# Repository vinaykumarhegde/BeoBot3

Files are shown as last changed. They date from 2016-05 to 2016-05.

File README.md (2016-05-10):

# BeoBot3

#### Mobile Robot for Indoor Navigation
--

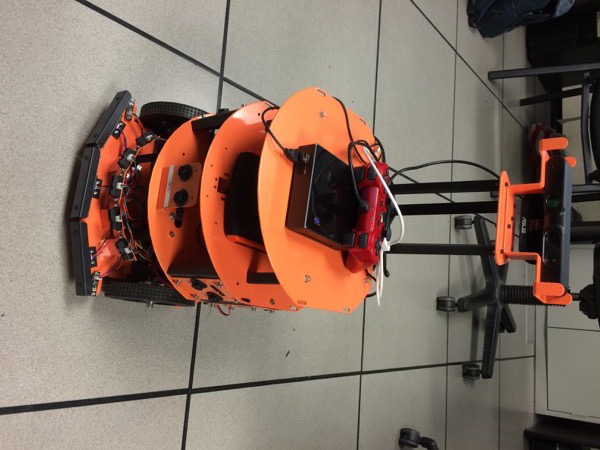
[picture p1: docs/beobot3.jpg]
BeoBot3


#### Specifications:
- Mobile base with wheel encoders
- 6 Ultrasound sensors for distance measurement
- 3 Front facing bumpers
- 11 IR sensors for distance measurement
- 4 Down facing IR sensors for cliff detection
- 1 Asus Xtion Pro Live RGBD camera
- Gigabyte iBrix mini PC with Ubuntu 14.04 and ROS Indigo

#### System Architecture:
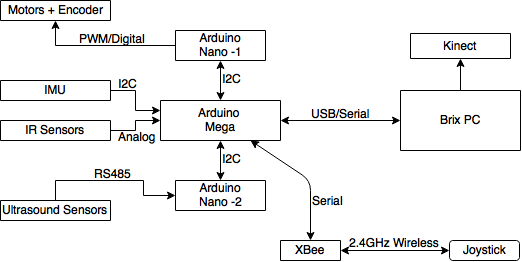
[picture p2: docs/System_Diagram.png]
Sys_arch


#### Software Components:
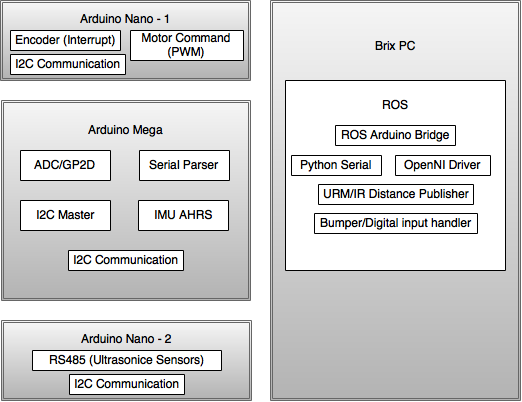
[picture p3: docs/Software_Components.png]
Sofware_components


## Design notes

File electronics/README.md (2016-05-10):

##BeoBot3
####Electronics
---

####Architecture:

####Resources:

* Schematic:
* Datasheets:

####Known Issues:
* Remove RS485 RX/TX jumpers while programming Nano-2. This connection is shared between programming interface (Serial) and MAX1348 (RS485 transciver).
* XBEE should always be on TTL1 port.
* Ignore TTL3/IMU markings on GMR board. 10-DOF IMU connects as I2C slave to Mega.
* ROS/Arduino Mega not responding:
	- Solution: This happens because Mega can not talk to nano-1 or nano-2. In the setup phase, Mega looks for I2C slaves to be connected. 
	- Also, make sure GMR board is powered ON. I2C pull up resistors use VCC from GMR board, not from USB connections.
* GMR Board has SX3478 and schematic has GS3478. This are pin compatible alternatives.

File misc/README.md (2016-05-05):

## BeoBot3 
#### Miscellaneous Files
---
This directory contains miscellaneous files used for the project. Designs for all 3D printed parts are stored here.

### Asus Xtio Pro Live Mount
This mount can be used to mount Asus Xtio Pro Live camera on the robot. This can be snapped on to rotating fixture on Asus Xtion camera.

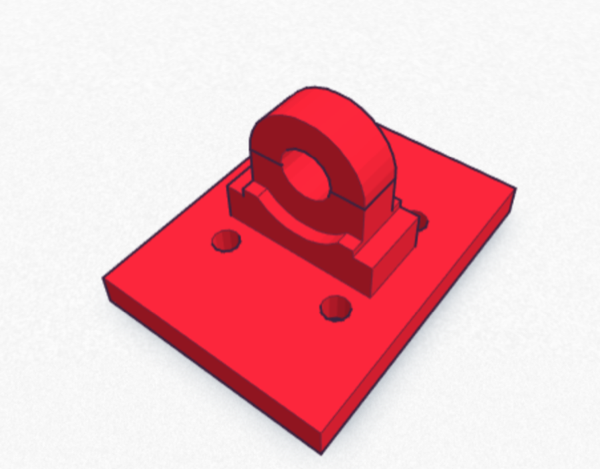
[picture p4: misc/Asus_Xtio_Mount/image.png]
Asus_Xtion


Design location: [Tinkercad](https://tinkercad.com/things/gU7ryKgmKkC) 

### Pan-Tilt Camera Mount
This mount is used to hold [ODROID webcam] (http://www.hardkernel.com/main/products/prdt_info.php?g_code=G137517754892) and has 2-Degrees of freedom for rotation. This uses [9G micro servos] (http://www.amazon.com/RioRand-micro-Helicopter-Airplane-Controls/dp/B00M8RGGFG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) for pan and tilt movements and can be controlled by PWM signal. 

This can be used to implement object tracking or surprise detection algorithm on robot.

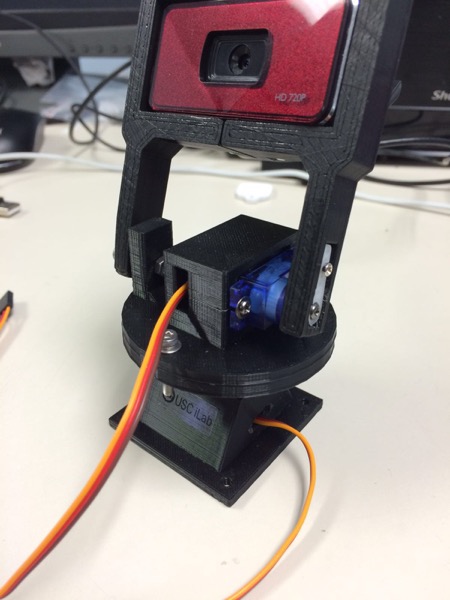
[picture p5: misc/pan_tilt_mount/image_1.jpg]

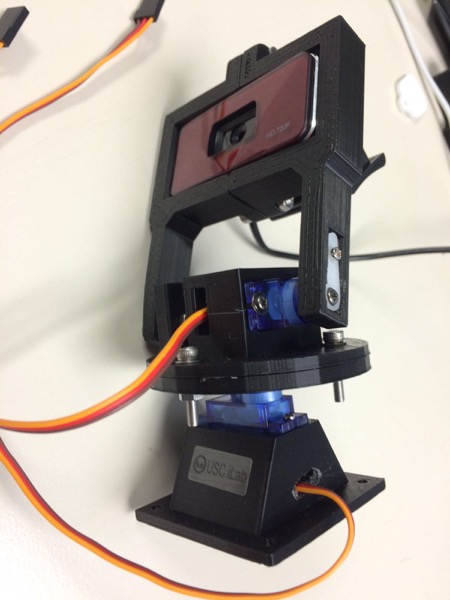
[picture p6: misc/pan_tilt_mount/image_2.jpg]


##### Important notes:
* [Datasheet] (http://www.micropik.com/PDF/SG90Servo.pdf)
* Connections:
	- Orange: PWM Input
	- Red: Vcc
	- Brown: Gnd
* Gears are very soft (they are plastic) and break if you try to twist it with force!
* Thingiverse link: [Thingiverse] (http://www.thingiverse.com/thing:1540658)

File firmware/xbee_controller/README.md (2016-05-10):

## HCR Robot RC Controller

RC Model: [DF Robot Wireless Gamepad V2.0](http://www.dfrobot.com/index.php?route=product/product&product_id=858#.Vwr5imNWKn0) [[Wiki]] (http://www.dfrobot.com/wiki/index.php/Wirless_GamePad_V2.0_(SKU:DFR0182))

### Gamepad:
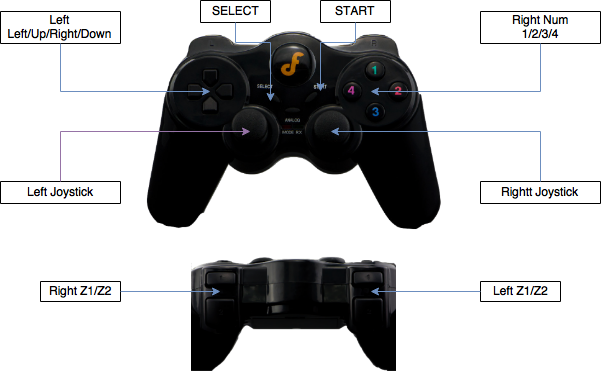
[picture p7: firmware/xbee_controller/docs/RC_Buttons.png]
RC_Buttons


### Specifications:
* Enable/Disable Robot
* Give Linear/Angular Velocities to Robot
* Emergency Stop
* Vibration Feedback

### Key Associations:

| Function | Key | 
| ---| --- |
| Start| Push and Hold START for 1 second |
| Emergency Stop | Right num (1) |
| Stop the robot | Left/Right Z1 |
| Linear Velocity | Left/Right Z2 + Left Joystick |
| Angular Velocity | Left/Right Z2 + Right Joystick | 
| Calibrate Joysticks | Left Z1 + Right num (2) |
| Change Linear Velocity| Right Z1 + Left Up/Down Arrow|
| Change Linear Velocity| Right Z1 + Left Left/Right Arrow|
| Enable ROS | Press and Hold SELECT for 3 seconds |

### TO-DO:
* Implement handshaking to ensure the commands are received by the robot.
* Adjust/fine-tune the joystick.

### Warning:
* Do not press ANALOG button. This freezes all the joystic buttons (Temporary fix: Restart the controller)
* (IMPORTANT!!) While connecting Arduino programming header, make sure the it's as shown in the image below: 

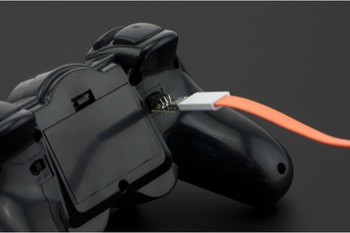
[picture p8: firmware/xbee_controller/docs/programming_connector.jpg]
Programming


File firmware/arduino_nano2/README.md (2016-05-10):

## HCRBot GMR n2 driver

URM04 driver.

Addresses:
 *      UR_L2N  - 0x11
 *      UR_L2NW - 0x12
 *      UR_L2NE - 0x13
 *      UR_L2S  - 0x14
 *      UR_L2SW - 0x15
 *      UR_L2SE - 0x16

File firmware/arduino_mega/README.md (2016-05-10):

### hcrbot_gmr_mega

##### History:
* Initial Version: [ROS Arduino Bridge](http://wiki.ros.org/ros_arduino_bridge)
* Current: Added Support for DFRobot HCRBot motor and encoders

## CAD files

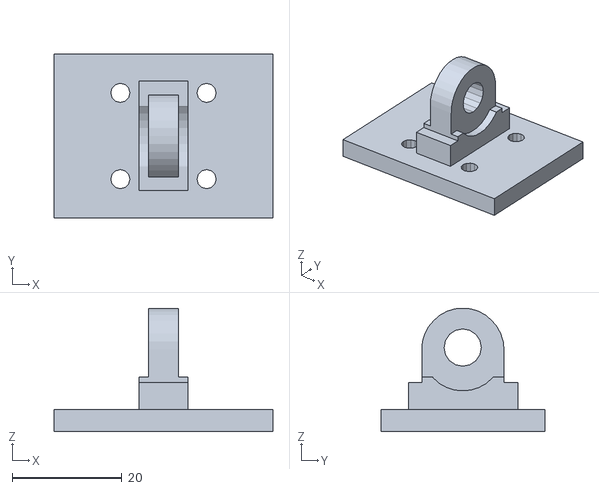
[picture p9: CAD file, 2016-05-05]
misc/Asus_Xtio_Mount/asus_xtion_pro_live_mount.stl
40.0 x 30.0 x 22.5

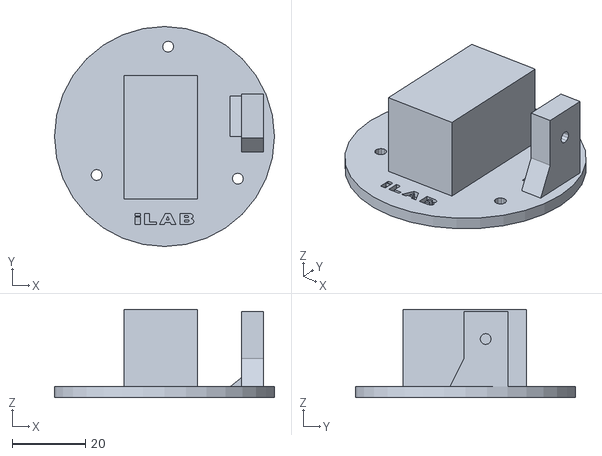
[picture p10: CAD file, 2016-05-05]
misc/pan_tilt_mount/pan-tilt-middle-plate-1.stl
60.0 x 60.0 x 24.1

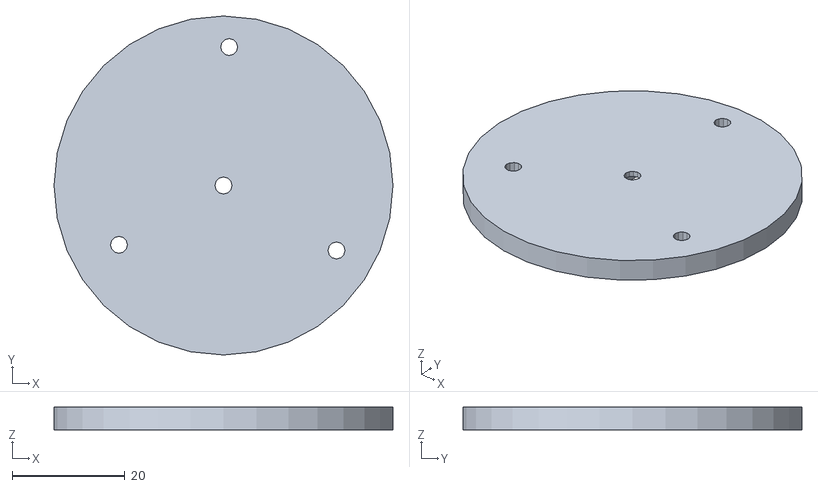
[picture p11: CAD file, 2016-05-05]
misc/pan_tilt_mount/pan-tilt-middle-plate-2.stl
60.0 x 60.0 x 4.00

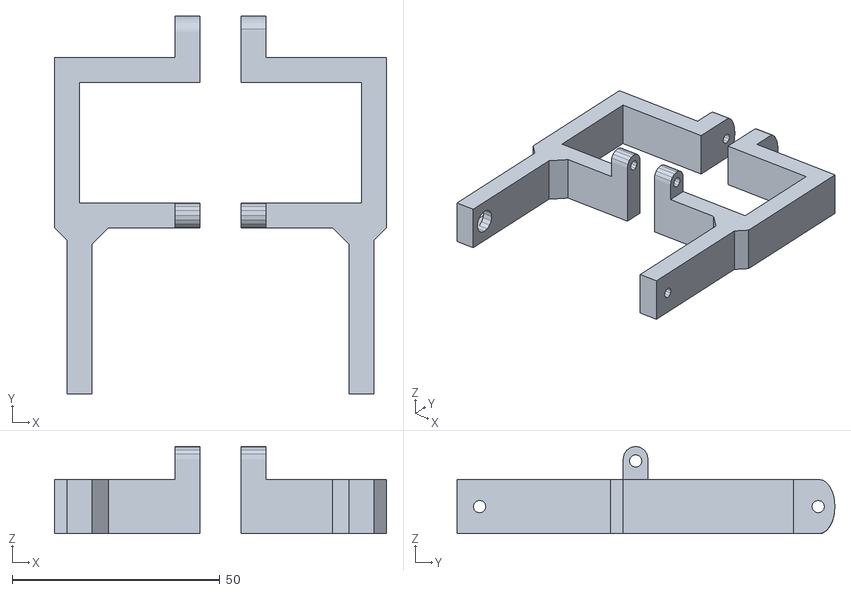
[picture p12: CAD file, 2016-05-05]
misc/pan_tilt_mount/pan-tilt-camera-holder.stl
80.0 x 91.0 x 21.0

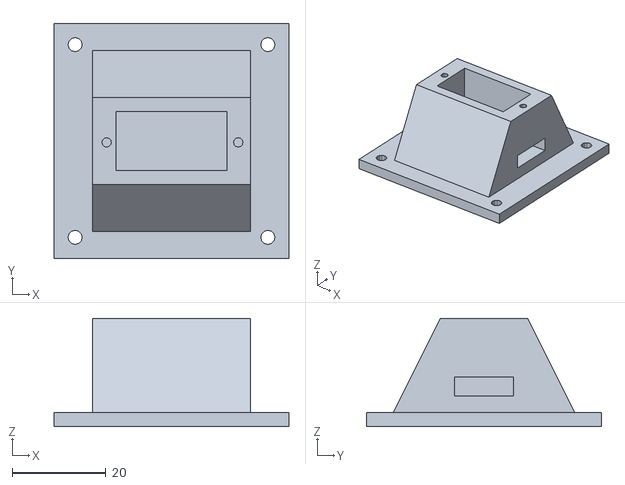
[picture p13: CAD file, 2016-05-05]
misc/pan_tilt_mount/pan-tilt-base.stl
50.0 x 50.0 x 23.0

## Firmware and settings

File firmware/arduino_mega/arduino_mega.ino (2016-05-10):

/*********************************************************************
 *  ROSArduinoBridge
 
    A set of simple serial commands to control a differential drive
    robot and receive back sensor and odometry data. Default 
    configuration assumes use of an Arduino Mega + Pololu motor
    controller shield + Robogaia Mega Encoder shield.  Edit the
    readEncoder() and setMotorSpeed() wrapper functions if using 
    different motor controller or encoder method.

    Created for the Pi Robot Project: http://www.pirobot.org
    and the Home Brew Robotics Club (HBRC): http://hbrobotics.org
    
    Authors: Patrick Goebel, James Nugen

    Inspired and modeled after the ArbotiX driver by Michael Ferguson
    
    Software License Agreement (BSD License)

    Copyright (c) 2012, Patrick Goebel.
    All rights reserved.

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
    THIS SOFTWARE IS PROVIDED BY THE COPYRIGHT HOLDERS AND CONTRIBUTORS
    "AS IS" AND ANY EXPRESS OR IMPLIED WARRANTIES, INCLUDING, BUT NOT
    LIMITED TO, THE IMPLIED WARRANTIES OF MERCHANTABILITY AND FITNESS
    FOR A PARTICULAR PURPOSE ARE DISCLAIMED. IN NO EVENT SHALL THE
    COPYRIGHT OWNER OR CONTRIBUTORS BE LIABLE FOR ANY DIRECT, INDIRECT,
    INCIDENTAL, SPECIAL, EXEMPLARY, OR CONSEQUENTIAL DAMAGES (INCLUDING,
    BUT NOT LIMITED TO, PROCUREMENT OF SUBSTITUTE GOODS OR SERVICES;
    LOSS OF USE, DATA, OR PROFITS; OR BUSINESS INTERRUPTION) HOWEVER
    CAUSED AND ON ANY THEORY OF LIABILITY, WHETHER IN CONTRACT, STRICT
    LIABILITY, OR TORT (INCLUDING NEGLIGENCE OR OTHERWISE) ARISING IN
    ANY WAY OUT OF THE USE OF THIS SOFTWARE, EVEN IF ADVISED OF THE
 *  POSSIBILITY OF SUCH DAMAGE.
 *********************************************************************/

#include <Wire.h>

#define USE_BASE      // Enable the base controller code
//#undef USE_BASE     // Disable the base controller code

/* Define the motor controller and encoder library you are using */
#ifdef USE_BASE
   /* The Pololu VNH5019 dual motor driver shield */
   //#define POLOLU_VNH5019

   /* The Pololu MC33926 dual motor driver shield */
   //#define POLOLU_MC33926

   /* DFRobot HCR GMR Board Arduino Nano-1 motor driver.*/
   #define DFRHCR_N1_DRIVER

   /* DFRobot HCR GMR Encoders attached to Nano 1*/
   #define DFRHCR_N1_ENCODER
   
   /* The RoboGaia encoder shield */
   //#define ROBOGAIA
   
   /* Encoders directly attached to Arduino board */
   //#define ARDUINO_ENC_COUNTER
#endif

//#define USE_SERVOS  // Enable use of PWM servos as defined in servos.h
#undef USE_SERVOS     // Disable use of PWM servos

/* Serial port baud rate */
#define BAUDRATE    115200

/* Maximum PWM signal */
#define MAX_PWM        255

#if defined(ARDUINO) && ARDUINO >= 100
#include "Arduino.h"
#else
#include "WProgram.h"
#endif

/* Include definition of serial commands */
#include "commands.h"

/* Sensor functions */
#include "sensors.h"

/* Include servo support if required */
#ifdef USE_SERVOS
   #include <Servo.h>
   #include "servos.h"
#endif

#ifdef USE_BASE
  /* Motor driver function definitions */
  #include "motor_driver.h"

  /* Encoder driver function definitions */
  #include "encoder_driver.h"

  /* PID parameters and functions */
  #include "diff_controller.h"

  /* Run the PID loop at 30 times per second */
  #define PID_RATE           100     // Hz

  /* Convert the rate into an interval */
  const int PID_INTERVAL = 1000 / PID_RATE;
  
  /* Track the next time we make a PID calculation */
  unsigned long nextPID = PID_INTERVAL;

  /* Stop the robot if it hasn't received a movement command
   in this number of milliseconds */
  #define AUTO_STOP_INTERVAL 2000
  long lastMotorCommand = AUTO_STOP_INTERVAL;
#endif

/* Variable initialization */

// A pair of varibles to help parse serial commands (thanks Fergs)
int arg = 0;
int index = 0;

// Variable to hold an input character
char chr;

// Variable to hold the current single-character command
char cmd;

// Character arrays to hold the first and second arguments
char argv1[16];
char argv2[16];

// The arguments converted to integers
long arg1;
long arg2;

// Variable for ROS compatibility
bool ROSEnabled = true;


/* Clear the current command parameters */
void resetCommand() {
  cmd = NULL;
  memset(argv1, 0, sizeof(argv1));
  memset(argv2, 0, sizeof(argv2));
  arg1 = 0;
  arg2 = 0;
  arg = 0;
  index = 0;
}

/* Run a command.  Commands are defined in commands.h */
int runCommand() {
  int i = 0;
  char *p = argv1;
  char *str;
  int pid_args[4];
  arg1 = atoi(argv1);
  arg2 = atoi(argv2);
  
  switch(cmd) {
  case GET_BAUDRATE:
    Serial.println(BAUDRATE);
    break;
  case ANALOG_READ:
    Serial.println(analogRead(arg1));
    break;
  case DIGITAL_READ:
    Serial.println(digitalRead(arg1));
    break;
  case ANALOG_WRITE:
    analogWrite(arg1, arg2);
    Serial.println("OK"); 
    break;
  case DIGITAL_WRITE:
    if (arg2 == 0) digitalWrite(arg1, LOW);
    else if (arg2 == 1) digitalWrite(arg1, HIGH);
    Serial.println("OK"); 
    break;
  case PIN_MODE:
    if (arg2 == 0) pinMode(arg1, INPUT);
    else if (arg2 == 1) pinMode(arg1, OUTPUT);
    Serial.println("OK");
    break;
  case PING:
    Serial.println(Ping(arg1));
    break;

//  case URM04:
//    char dsfg = readURM();
//    for(){
//      Serial.write();
//    } 
//    Serial.print("\n");
//    Serial.println("OK");
//    break;
#ifdef USE_SERVOS
  case SERVO_WRITE:
    servos[arg1].write(arg2);
    Serial.println("OK");
    break;
  case SERVO_READ:
    Serial.println(servos[arg1].read());
    break;
#endif
    
#ifdef USE_BASE
  case READ_ENCODERS:
    Serial.print(readEncoder(LEFT));
    Serial.print(" ");
    Serial.println(readEncoder(RIGHT));
    break;
   case RESET_ENCODERS:
    resetEncoders();
    resetPID();
    Serial.println("OK");
    break;
  case MOTOR_SPEEDS:
    /* Reset the auto stop timer */
    lastMotorCommand = millis();
    if (arg1 == 0 && arg2 == 0) {
      setMotorSpeeds(0, 0);
      moving = 0;
    }
    else moving = 1;
    leftPID.TargetTicksPerFrame = arg1;
    rightPID.TargetTicksPerFrame = arg2;
    Serial.println("OK"); 
    break;
  case UPDATE_PID:
    while ((str = strtok_r(p, ":", &p)) != '\0') {
       pid_args[i] = atoi(str);
       i++;
    }
    Kp = pid_args[0];
    Kd = pid_args[1];
    Ki = pid_args[2];
    Ko = pid_args[3];
    Serial.println("OK");
    break;
#endif
  default:
    Serial.println("Invalid Command");
    break;
  }
}

/* Setup function--runs once at startup. */
void setup() {
  Serial.begin(BAUDRATE);
  Serial1.begin(BAUDRATE);

// Initialize the motor controller if used */
#ifdef USE_BASE
  #ifdef ARDUINO_ENC_COUNTER
    //set as inputs
    DDRD &= ~(1<<LEFT_ENC_PIN_A);
    DDRD &= ~(1<<LEFT_ENC_PIN_B);
    DDRC &= ~(1<<RIGHT_ENC_PIN_A);
    DDRC &= ~(1<<RIGHT_ENC_PIN_B);
    
    //enable pull up resistors
    PORTD |= (1<<LEFT_ENC_PIN_A);
    PORTD |= (1<<LEFT_ENC_PIN_B);
    PORTC |= (1<<RIGHT_ENC_PIN_A);
    PORTC |= (1<<RIGHT_ENC_PIN_B);
    
    // tell pin change mask to listen to left encoder pins
    PCMSK2 |= (1 << LEFT_ENC_PIN_A)|(1 << LEFT_ENC_PIN_B);
    // tell pin change mask to listen to right encoder pins
    PCMSK1 |= (1 << RIGHT_ENC_PIN_A)|(1 << RIGHT_ENC_PIN_B);
    
    // enable PCINT1 and PCINT2 interrupt in the general interrupt mask
    PCICR |= (1 << PCIE1) | (1 << PCIE2);
  #elif defined DFRHCR_N1_ENCODER
    Serial.println("Master Arduino started...");
    Wire.begin();
  #endif
  initMotorController();
  resetPID();
#endif
/* Attach servos if used */
#ifdef USE_SERVOS
  int i;
  for (i = 0; i < N_SERVOS; i++) {
    servos[i].attach(servoPins[i]);
  }
#endif
  
}


/* Enter the main loop.  Read and parse input from the serial port
   and run any valid commands. Run a PID calculation at the target
   interval and check for auto-stop conditions.
*/
void loop() {
  if(Serial1.available()){
    bool ROSEnabled = false;
    while(Serial1.available()){
    // Read the next character
    chr = Serial1.read();
    Serial.print(chr);
    // Terminate a command with a CR
    if(chr == '!'){
      // Enable the ROS functionality
      ROSEnabled = true;
    }
    else if (chr == 13) {
      if (arg == 1) argv1[index] = NULL;
      else if (arg == 2) argv2[index] = NULL;
      runCommand();
      resetCommand();
    }
    // Use spaces to delimit parts of the command
    else if (chr == ' ') {
      // Step through the arguments
      if (arg == 0) arg = 1;
      else if (arg == 1)  {
        argv1[index] = NULL;
        arg = 2;
        index = 0;
      }
      continue;
    }
    else {
      if (arg == 0) {
        // The first arg is the single-letter command
        cmd = chr;
      }
      else if (arg == 1) {
        // Subsequent arguments can be more than one character
        argv1[index] = chr;
        index++;
      }
      else if (arg == 2) {
        argv2[index] = chr;
        index++;
      }
    }    
    }
  }
  
  while (ROSEnabled && Serial.available() > 0) {
    // Read the next character
    chr = Serial.read();

    // Terminate a command with a CR
    if (chr == 13) {
      if (arg == 1) argv1[index] = NULL;
      else if (arg == 2) argv2[index] = NULL;
      runCommand();
      resetCommand();
    }
    // Use spaces to delimit parts of the command
    else if (chr == ' ') {
      // Step through the arguments
      if (arg == 0) arg = 1;
      else if (arg == 1)  {
        argv1[index] = NULL;
        arg = 2;
        index = 0;
      }
      continue;
    }
    else {
      if (arg == 0) {
        // The first arg is the single-letter command
        cmd = chr;
      }
      else if (arg == 1) {
        // Subsequent arguments can be more than one character
        argv1[index] = chr;
        index++;
      }
      else if (arg == 2) {
        argv2[index] = chr;
        index++;
      }
    }
  }
  
// If we are using base control, run a PID calculation at the appropriate intervals
#ifdef USE_BASE
  if (millis() > nextPID) {
    updatePID();
    nextPID += PID_INTERVAL;
  }
  
  // Check to see if we have exceeded the auto-stop interval
  if ((millis() - lastMotorCommand) > AUTO_STOP_INTERVAL) {;
    setMotorSpeeds(0, 0);
    moving = 0;
  }

#endif
}

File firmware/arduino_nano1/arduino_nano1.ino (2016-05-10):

/*
 * Program for Nano 1
 * 
 */

#include <Wire.h>
//#define LOGGING 1
#undef LOGGING


// Pins
#define R_PWM 9  //M1 Speed Control
#define L_PWM 11 //M2 Speed Control
#define R_DIR 8  //M1 Direction Control
#define L_DIR 10 //M1 Direction Control
#define R_ENC_OTHER 4 // Encoder Pin A
#define R_ENC_INT 2 // Int 0; Encode Pin B
#define L_ENC_INT 3 // Int 1; Encoder Pin A
#define L_ENC_OTHER 5 //Encode Pin B

#define MINPWM 50 //Minimum PWM for the motor, below this static friction stops the motor from spinning
#define STATICPULSEWIDTH 100 //Pulse time to avoid static friction in gears.

// Buffers
#define CMDBUFFER 10 // Command buffer.

// Other
#define MAXSPEED 100 // In mm/s
#define BASEWIDTH 285 // in mm
#define WHEELDIAMETER 136 // in mm
#define N1_I2C_ADDR 0x10
#define BAUDRATE 115200


// Variables
volatile long lTicks;
volatile long rTicks;

void leftTicks(){
  if(digitalRead(L_ENC_OTHER))
    lTicks--;
  else
    lTicks++;
}

// Clockwise rotation will increment ticks and 
// anti clockwise will decrease the count
void rightTicks(){
  if(digitalRead(R_ENC_OTHER))
    rTicks++;
  else
    rTicks--;
}

void readPWMInput(int bytes){
  byte inArray[4];
  if(Wire.available() == 4){
    for(int i=0;i<4;i++)
      inArray[i] = Wire.read();
  }
  else if(Wire.available() == 1){
    // Reset command sent:
    char c = Wire.read();
    if(c == 'r'){
      rTicks = 0;
      return;
    }
    if(c == 'l'){
      lTicks = 0;
      return;
    }
    return;
  }
  else{
#ifdef LOGGING
  Serial.println("Incorrect I2C bytes sent");
#endif
  }
  int rPWM = (inArray[0]) + (int(inArray[1]) << 8);
  int lPWM = (inArray[2]) + (int(inArray[3]) << 8);

  bool rDir = true;
  bool lDir = false;

#ifdef LOGGING
  Serial.print("R: ");
  rDir?Serial.print("F "):Serial.print("B ");
  Serial.print(rPWM,HEX);
  Serial.print("\tL: ");
  lDir?Serial.print("B "):Serial.print("F ");
  Serial.print(lPWM,HEX);
  Serial.println("");
#endif  
  if(rPWM < 0){
    rPWM = -rPWM;
    rDir = false;
  }
  if(lPWM < 0){
    lPWM = -lPWM;
    lDir = true;
  }

  (rDir)? digitalWrite(R_DIR,LOW):digitalWrite(R_DIR,HIGH);
  if(rPWM > 255)
    rPWM = 255;
  if(rPWM > 0 && rPWM < MINPWM){
    analogWrite(R_PWM, uint8_t(MINPWM));
    delay(STATICPULSEWIDTH);
  }
  analogWrite(R_PWM,uint8_t(rPWM));
  
  (lDir)? digitalWrite(L_DIR,LOW):digitalWrite(L_DIR,HIGH);
  if(lPWM > 255)
    lPWM = 255;
  if(lPWM > 0 && lPWM < MINPWM){
    analogWrite(L_PWM, uint8_t(MINPWM));
    delay(STATICPULSEWIDTH);
  }
  analogWrite(L_PWM,uint8_t(lPWM));  
}

void sendEncReadings(){
  uint8_t ticks[8];

  ticks[0] = (rTicks) & 0xFF;
  ticks[1] = (rTicks >> 8) & 0xFF;
  ticks[2] = (rTicks >> 16) & 0xFF;
  ticks[3] = (rTicks >> 24) & 0xFF;

  ticks[4] = (lTicks) & 0xFF;
  ticks[5] = (lTicks >> 8) & 0xFF;
  ticks[6] = (lTicks >> 16) & 0xFF;
  ticks[7] = (lTicks >> 24) & 0xFF;

#ifdef LOGGING
//  Serial.print("Sending Encoder value: ");
//  for(int i=3; i>=0;i--)
//    Serial.print(ticks[i],HEX);
//  Serial.print("\t");
//  for(int i=7; i>=4;i--)
//    Serial.print(ticks[i],HEX);
//  Serial.println(".");
//  Serial.print(rTicks);
//  Serial.print("\t");
//  Serial.println(lTicks);
#endif

  // Send 8 bytes of ticks data
  Wire.write(ticks,8);
}

void setup() {
  // put your setup code here, to run once:
#ifdef LOGGING
  Serial.begin(BAUDRATE);
  Serial.println("Serial monitor for Nano-1 started...");
#endif
  Wire.begin(N1_I2C_ADDR);
  Wire.onReceive(readPWMInput);
  Wire.onRequest(sendEncReadings);
  attachInterrupt(1, leftTicks, RISING);
  attachInterrupt(0, rightTicks, RISING);

  pinMode(R_PWM,OUTPUT);
  pinMode(L_PWM,OUTPUT);
  pinMode(R_DIR,OUTPUT);
  pinMode(L_DIR,OUTPUT);

  pinMode(R_ENC_OTHER,INPUT);
  pinMode(L_ENC_OTHER,INPUT);
}

void loop() {
  // put your main code here, to run repeatedly:
#ifdef LOGGING
//  Serial.print("Right encoder: ");
//  Serial.print(rTicks);
//  Serial.print("\tLeft encoder: ");
//  Serial.print(lTicks);
//  Serial.println(".");
#endif
  delay(1000);

}

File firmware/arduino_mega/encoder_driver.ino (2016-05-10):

/* *************************************************************
   Encoder definitions
   
   Add a "#if defined" block to this file to include support for
   a particular encoder board or library. Then add the appropriate
   #define near the top of the main ROSArduinoBridge.ino file.
   
   ************************************************************ */

#include "encoder_driver.h"
#include "motor_driver.h"

#ifdef USE_BASE

#if defined ROBOGAIA
  /* The Robogaia Mega Encoder shield */
  #include "MegaEncoderCounter.h"

  /* Create the encoder shield object */
  MegaEncoderCounter encoders = MegaEncoderCounter(4); // Initializes the Mega Encoder Counter in the 4X Count mode
  
  /* Wrap the encoder reading function */
  long readEncoder(int i) {
    if (i == LEFT) return encoders.YAxisGetCount();
    else return encoders.XAxisGetCount();
  }

  /* Wrap the encoder reset function */
  void resetEncoder(int i) {
    if (i == LEFT) return encoders.YAxisReset();
    else return encoders.XAxisReset();
  }
#elif defined ARDUINO_ENC_COUNTER
  volatile long left_enc_pos = 0L;
  volatile long right_enc_pos = 0L;
  static const int8_t ENC_STATES [] = {0,1,-1,0,-1,0,0,1,1,0,0,-1,0,-1,1,0};  //encoder lookup table
    
  /* Interrupt routine for LEFT encoder, taking care of actual counting */
  ISR (PCINT2_vect){
  	static uint8_t enc_last=0;
        
	enc_last <<=2; //shift previous state two places
	enc_last |= (PIND & (3 << 2)) >> 2; //read the current state into lowest 2 bits
  
  	left_enc_pos += ENC_STATES[(enc_last & 0x0f)];
  }
  
  /* Interrupt routine for RIGHT encoder, taking care of actual counting */
  ISR (PCINT1_vect){
        static uint8_t enc_last=0;
          	
	enc_last <<=2; //shift previous state two places
	enc_last |= (PINC & (3 << 4)) >> 4; //read the current state into lowest 2 bits
  
  	right_enc_pos += ENC_STATES[(enc_last & 0x0f)];
  }
  
  /* Wrap the encoder reading function */
  long readEncoder(int i) {
    if (i == LEFT) return left_enc_pos;
    else return right_enc_pos;
  }

  /* Wrap the encoder reset function */
  void resetEncoder(int i) {
    if (i == LEFT){
      left_enc_pos=0L;
      return;
    } else { 
      right_enc_pos=0L;
      return;
    }
  }

#elif defined DFRHCR_N1_ENCODER
/*
 * This portion defines the encoder reading from Nano 1 
 */
  volatile long rTicks = 0L;
  volatile long lTicks = 0L;
  
  /* Encoder reading function*/
  long readEncoder(int i){
    Wire.requestFrom(N1_I2C_ADDR,8);
    int bytes = Wire.available();
    if(bytes == 8){
      byte _t[8];
      for(int i=0; i<8; i++)
        _t[i] = Wire.read();
      rTicks = (long(_t[3]) << 24) + (long(_t[2]) << 16) + (long(_t[1]) << 8) + (long(_t[0]));
      lTicks = (long(_t[7]) << 24) + (long(_t[6]) << 16) + (long(_t[5]) << 8) + (long(_t[4]));
    } else {
#ifdef LOGGING 
      Serial.println("Wrong number of bytes sent from Nano 1");
      Serial.print("Slave sent: "); Serial.print(bytes,DEC);
      Serial.println(" bytes");
#endif
    }
    if(i==LEFT) return lTicks;
    else return rTicks;
  }

  /* Wrap the encoder reset function */
  void resetEncoder(int i) {
    if (i == LEFT){
      lTicks=0L;
      Wire.beginTransmission(N1_I2C_ADDR);
      Wire.write('l');
      Wire.endTransmission(N1_I2C_ADDR);
      return;
    } else { 
      rTicks=0L;
      Wire.beginTransmission(N1_I2C_ADDR);
      Wire.write('r');
      Wire.endTransmission(N1_I2C_ADDR);
      return;
    }
  }

#else
  #error A encoder driver must be selected!
#endif

/* Wrap the encoder reset function */
void resetEncoders() {
  resetEncoder(LEFT);
  resetEncoder(RIGHT);
}

#endif

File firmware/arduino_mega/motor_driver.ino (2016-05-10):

/***************************************************************
   Motor driver definitions
   
   Add a "#elif defined" block to this file to include support
   for a particular motor driver.  Then add the appropriate
   #define near the top of the main ROSArduinoBridge.ino file.
   
   *************************************************************/
#include "motor_driver.h"

#ifdef USE_BASE
   
#if defined POLOLU_VNH5019
  /* Include the Pololu library */
  #include "DualVNH5019MotorShield.h"

  /* Create the motor driver object */
  DualVNH5019MotorShield drive;
  
  /* Wrap the motor driver initialization */
  void initMotorController() {
    drive.init();
  }

  /* Wrap the drive motor set speed function */
  void setMotorSpeed(int i, int spd) {
    if (i == LEFT) drive.setM1Speed(spd);
    else drive.setM2Speed(spd);
  }

  // A convenience function for setting both motor speeds
  void setMotorSpeeds(int leftSpeed, int rightSpeed) {
    setMotorSpeed(LEFT, leftSpeed);
    setMotorSpeed(RIGHT, rightSpeed);
  }
#elif defined POLOLU_MC33926
  /* Include the Pololu library */
  #include "DualMC33926MotorShield.h"

  /* Create the motor driver object */
  DualMC33926MotorShield drive;
  
  /* Wrap the motor driver initialization */
  void initMotorController() {
    drive.init();
  }

  /* Wrap the drive motor set speed function */
  void setMotorSpeed(int i, int spd) {
    if (i == LEFT) drive.setM1Speed(spd);
    else drive.setM2Speed(spd);
  }

  // A convenience function for setting both motor speeds
  void setMotorSpeeds(int leftSpeed, int rightSpeed) {
    setMotorSpeed(LEFT, leftSpeed);
    setMotorSpeed(RIGHT, rightSpeed);
  }

#elif defined DFRHCR_N1_DRIVER

  void initMotorController(){
    
  }
  
  /* Wrap the drive motor set speed function */
  void setMotorSpeed(int i, int spd) {
    // Empty function. This is not supported by motor driver.
  }

  // A convenience function for setting both motor speeds
  void setMotorSpeeds(int leftSpeed, int rightSpeed) {
    byte i2cSend[4];
    i2cSend[0] = (rightSpeed) & 0xFF;
    i2cSend[1] = (rightSpeed >> 8) & 0xFF;
    i2cSend[2] = (leftSpeed) & 0xFF;
    i2cSend[3] = (leftSpeed >> 8) & 0xFF;

    Wire.beginTransmission(N1_I2C_ADDR);
    Wire.write(i2cSend,4);
    Wire.endTransmission(N1_I2C_ADDR);
  }


#else
  #error A motor driver must be selected!
#endif

#endif

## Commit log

2016-04-22 add ROS arduino bridge reference
2016-05-02 add i2c request, change baudrate to 115200
2016-05-05 updated misc files readme
    [asus_xtion_pro_live_mount.stl, pan-tilt-base.stl, pan-tilt-camera-holder.stl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]
2016-05-10 rename arduino_mega
2016-05-10 rename arduino_nano1
